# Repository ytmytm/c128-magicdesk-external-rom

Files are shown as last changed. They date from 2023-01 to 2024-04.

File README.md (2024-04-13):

# MagicDesk-like External ROM cartridge for C128

This is a clone of [Magic Desk 512k](https://github.com/msolajic/c64-magic-desk-512k) by Marko Šolajić
converted to KiCad 6 format and modified to work as an External ROM cartridge for C128 and map 32K of ROM at a time.

It is supported by [Magic cartridge generator](https://bitbucket.org/zzarko/magic-cartridge-generator/src/main/).

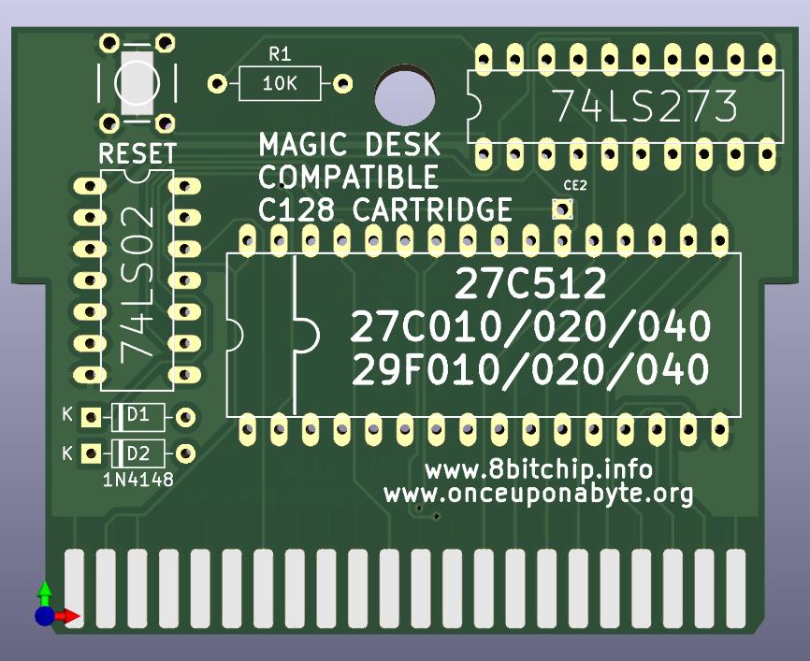
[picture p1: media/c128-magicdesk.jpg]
C128 External Function ROM cartridge


<a href="https://www.pcbway.com/project/shareproject/MagicDesk_like_External_ROM_cartridge_for_C128_43b0904b.html">PCB from PCBWay</a>

## Other options

There are two other projects [Magic Desk 128](https://github.com/RetroNynjah/Magic-Desk-128) and [Gmod2 (128)](https://www.freepascal.org/~daniel/gmod2/)
with a similar goal, but both map only 16K at a time. This makes it impossible e.g. to put The Servant on such cartridge.

## Why

It just seems much more useful in C128 mode to have whole 32K available - just like Internal Function ROM, but easily switched.
Since MMU can bank in/out both 16K halves ($8000-$BFFF) and ($C000-$FFFF) separately it seems that e.g. GEOS 128 could run directly from ROM bypassing any boot or loading parts.

## Hardware

The [schematic is here](kicad/plots/c128-magicdesk.pdf).

The main difference to C64 version is that this cartridge is meant for C128, so `/EXROM` signal is no longer connected to prevent from entering C64 mode automatically.

Two diodes and a pullup resistor perform AND function on `/ROML` and `/ROMH` to map 32K at a time ($8000-$FFFF).

Because the bank size is now 32K instead of 8K the lowest two bits of control register are not connected.

[kicad](kicad/) folder contains all the KiCad 6.0 project files and [kicad/plots](kicad/plots) all the Gerber files needed to produce PCB.

Please read the notes from the [original project](https://github.com/msolajic/c64-magic-desk-512k). The jumper configuration for various EPROMS/EEPROMS/FLASH chips is exactly the same, as well as possible expansion to 1MB.

## Programming

Data from ROM will appear as External Function ROM mapped in $8000-$FFFF area (32K).

ROM banks can be changed from BASIC.

```
BANK15:POKEDEC("DE00"),4*<rom bank>
```

There are 16 banks in a 512K EEPROM and 32 banks if you piggy-back two of them and connect `/CE2` signal as described for C64 Magic Desk 512K.

RESET will always enable bank 0.

It's easy to check the ROM data from C128 monitor, just use `8` as the bank number:

```
M 88000 880FF
```

Reading from $DE00 register will switch bank to a random value (what happened to be on the data bus), don't do that.

## Cartrige ROM generator

[Magic cartridge generator](https://bitbucket.org/zzarko/magic-cartridge-generator/src/main/) supports 32K banks, use `-832` option instead of `-8` when building ROM image.

A simple code snippet for a true C128 cartridge (internal/external function ROM) code to load and start BASIC program can be found on [World of Jani page](http://blog.worldofjani.com/?p=1600).

[Gmod2 Commodore 128 technical manual](https://www.freepascal.org/~daniel/gmod2/gmod2-c128.pdf) is also a useful resource.

You can also put The Servant on it. Preferably [the updated one that supports SD2IEC subdirectories and disk images](https://github.com/ytmytm/c128-theservant-sd2iec).

## Emulator Support

None yet :)

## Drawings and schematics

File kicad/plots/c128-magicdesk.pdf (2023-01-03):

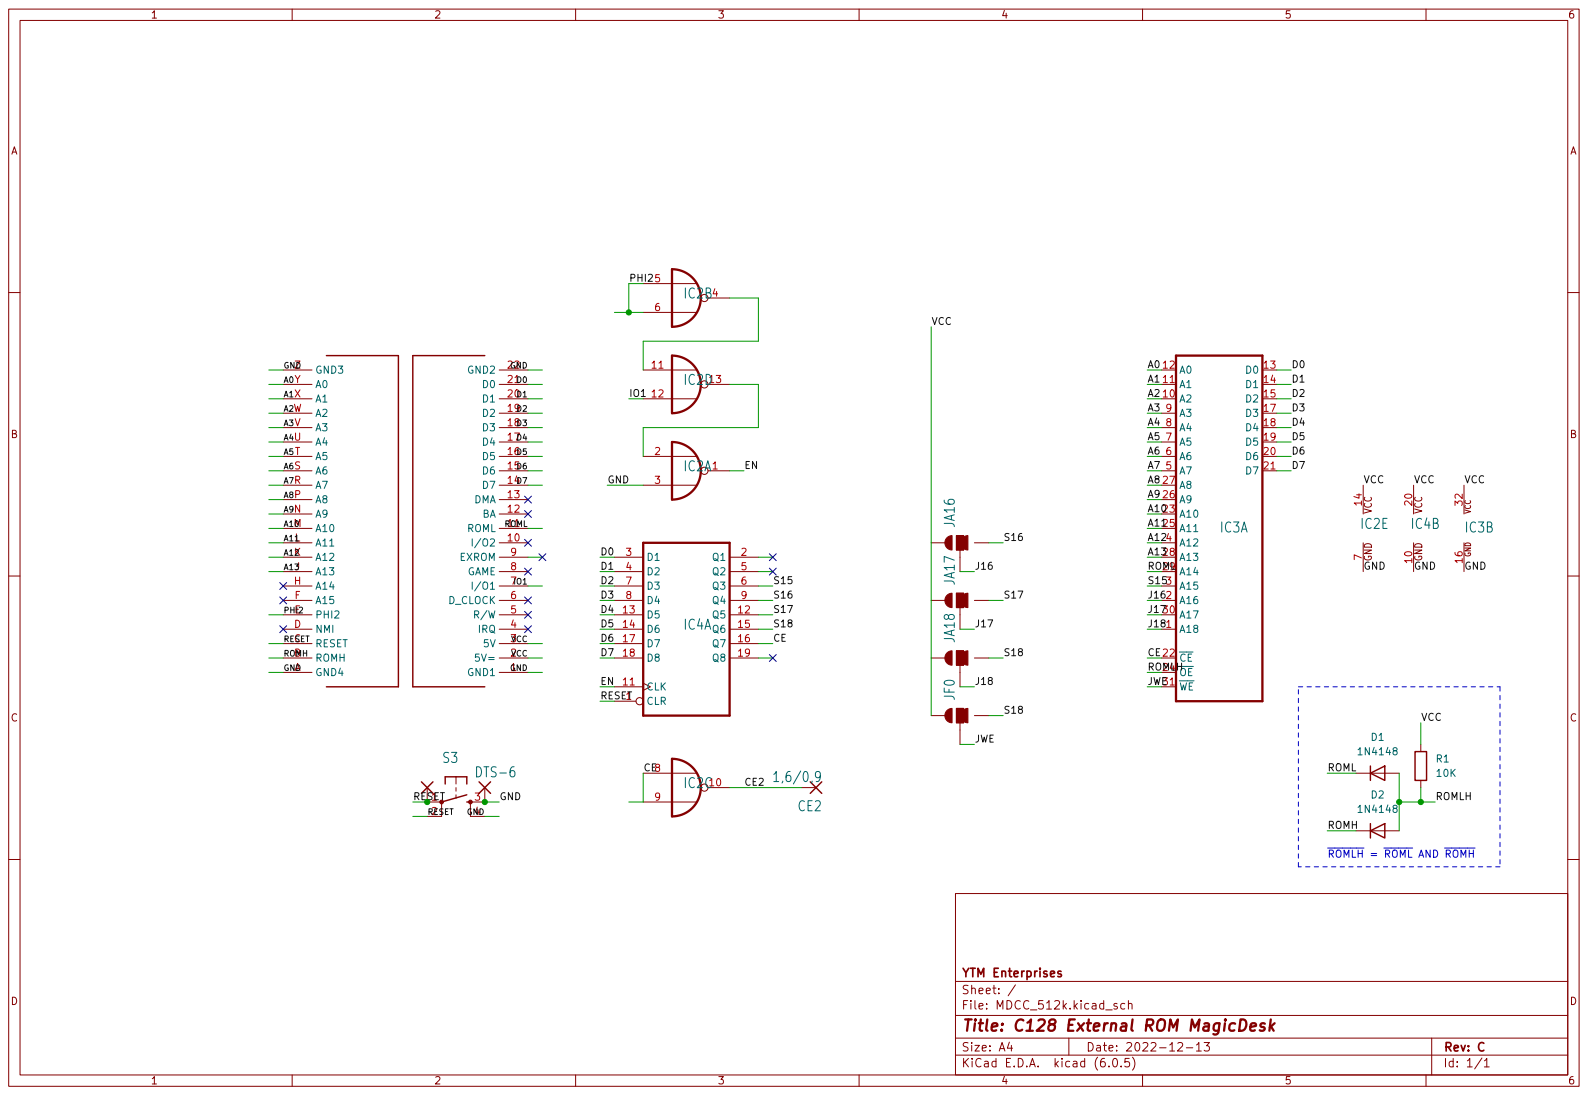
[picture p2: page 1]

~{ROMLH} = ~{ROML} AND ~{ROMH}

File: MDCC_512k.kicad_sch Sheet: / YTM Enterprises

Id: 1/1 Title: C128 External ROM MagicDesk

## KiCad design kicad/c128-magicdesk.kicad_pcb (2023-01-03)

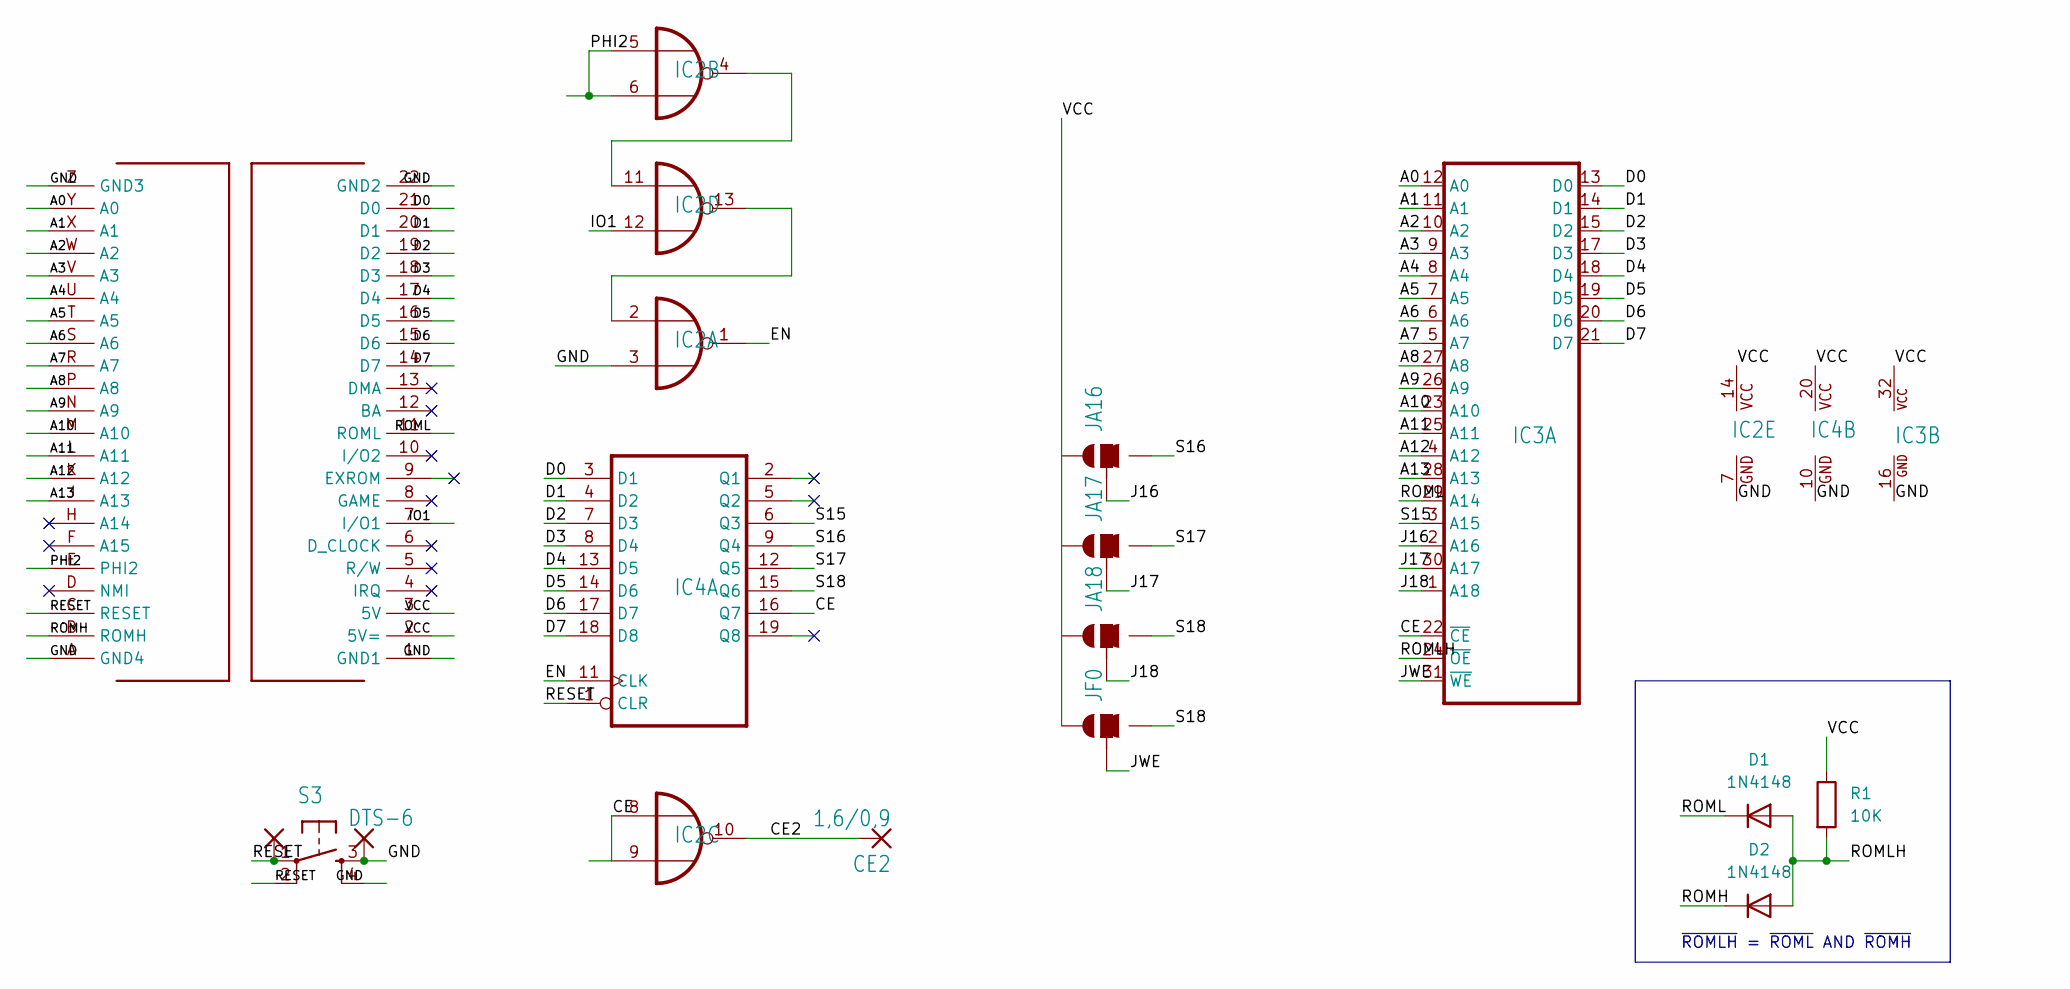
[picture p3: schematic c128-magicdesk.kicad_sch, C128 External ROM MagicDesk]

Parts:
CE2: 1,6/0,9; 1,6_0,9
D1, D2: 1N4148; D_DO-35_SOD27_P7.62mm_Horizontal
IC2: 74LS02; DIL14
IC3: 29F040; DIL32-6
IC4: 74LS273; DIL20
JA16, JA17, JA18: SOLDERJUMPER_2WAYS; SJ_3
JF0: SOLDERJUMPER_2WAYS; SJ_3
PAD1, PAD2: SMD5; SMD2,54-5,08
R1: 10K; R_Axial_DIN0207_L6.3mm_D2.5mm_P10.16mm_Horizontal
S3: DTS-6
U$1: C64_EXPANSION__CARTRIDGE

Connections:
/A0: IC3.12 (A0), U$1.Y (A0)
/A1: IC3.11 (A1), U$1.X (A1)
/A2: IC3.10 (A2), U$1.W (A2)
/A3: IC3.9 (A3), U$1.V (A3)
/A4: IC3.8 (A4), U$1.U (A4)
/A5: IC3.7 (A5), U$1.T (A5)
/A6: IC3.6 (A6), U$1.S (A6)
/A7: IC3.5 (A7), U$1.R (A7)
/A8: IC3.27 (A8), U$1.P (A8)
/A9: IC3.26 (A9), U$1.N (A9)
/A10: IC3.23 (A10), U$1.M (A10)
/A11: IC3.25 (A11), U$1.L (A11)
/A12: IC3.4 (A12), U$1.K (A12)
/A13: IC3.28 (A13), U$1.J (A13)
/CE: IC2.8 (I0), IC2.9 (I1), IC3.22 (~CE), IC4.16 (Q7)
/CE2: CE2.1, IC2.10 (O)
/D0: IC3.13 (D0), IC4.3 (D1), U$1.21 (D0)
/D1: IC3.14 (D1), IC4.4 (D2), U$1.20 (D1)
/D2: IC3.15 (D2), IC4.7 (D3), U$1.19 (D2)
/D3: IC3.17 (D3), IC4.8 (D4), U$1.18 (D3)
/D4: IC3.18 (D4), IC4.13 (D5), U$1.17 (D4)
/D5: IC3.19 (D5), IC4.14 (D6), U$1.16 (D5)
/D6: IC3.20 (D6), IC4.17 (D7), U$1.15 (D6)
/D7: IC3.21 (D7), IC4.18 (D8), U$1.14 (D7)
/EN: IC2.1 (O), IC4.11 (CLK)
/GND: IC2.3 (I1), IC2.7 (GND), IC3.16 (GND), IC4.10 (GND), PAD2.1, S3.3, S3.4, U$1.1 (GND1), U$1.22 (GND2), U$1.A (GND4), U$1.Z (GND3)
/IO1: IC2.12 (I1), U$1.7 (I/O1)
/J16: IC3.2 (A16), JA16.2
/J17: IC3.30 (A17), JA17.2
/J18: IC3.1 (A18), JA18.2
/JWE: IC3.31 (~WE), JF0.2
/PHI2: IC2.5 (I0), IC2.6 (I1), U$1.E (PHI2)
/RESET: IC4.1 (CLR), PAD1.1, S3.1, S3.2, U$1.C (RESET)
/ROMH: D2.1 (K), U$1.B (ROMH)
/ROML: D1.1 (K), IC3.29 (A14), U$1.11 (ROML)
/ROMLH: D1.2 (A), D2.2 (A), IC3.24 (~OE), R1.2
/S15: IC3.3 (A15), IC4.6 (Q3)
/S16: IC4.9 (Q4), JA16.3
/S17: IC4.12 (Q5), JA17.3
/S18: IC4.15 (Q6), JA18.3, JF0.3
/VCC: IC2.14 (VCC), IC3.32 (VCC), IC4.20 (VCC), JA16.1, JA17.1, JA18.1, JF0.1, R1.1, U$1.2 (5V=), U$1.3 (5V)
unnamed: IC2.4 (O), IC2.11 (I0)
unnamed: IC2.2 (I0), IC2.13 (O)

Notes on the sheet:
~{ROMLH} = ~{ROML} AND ~{ROMH}

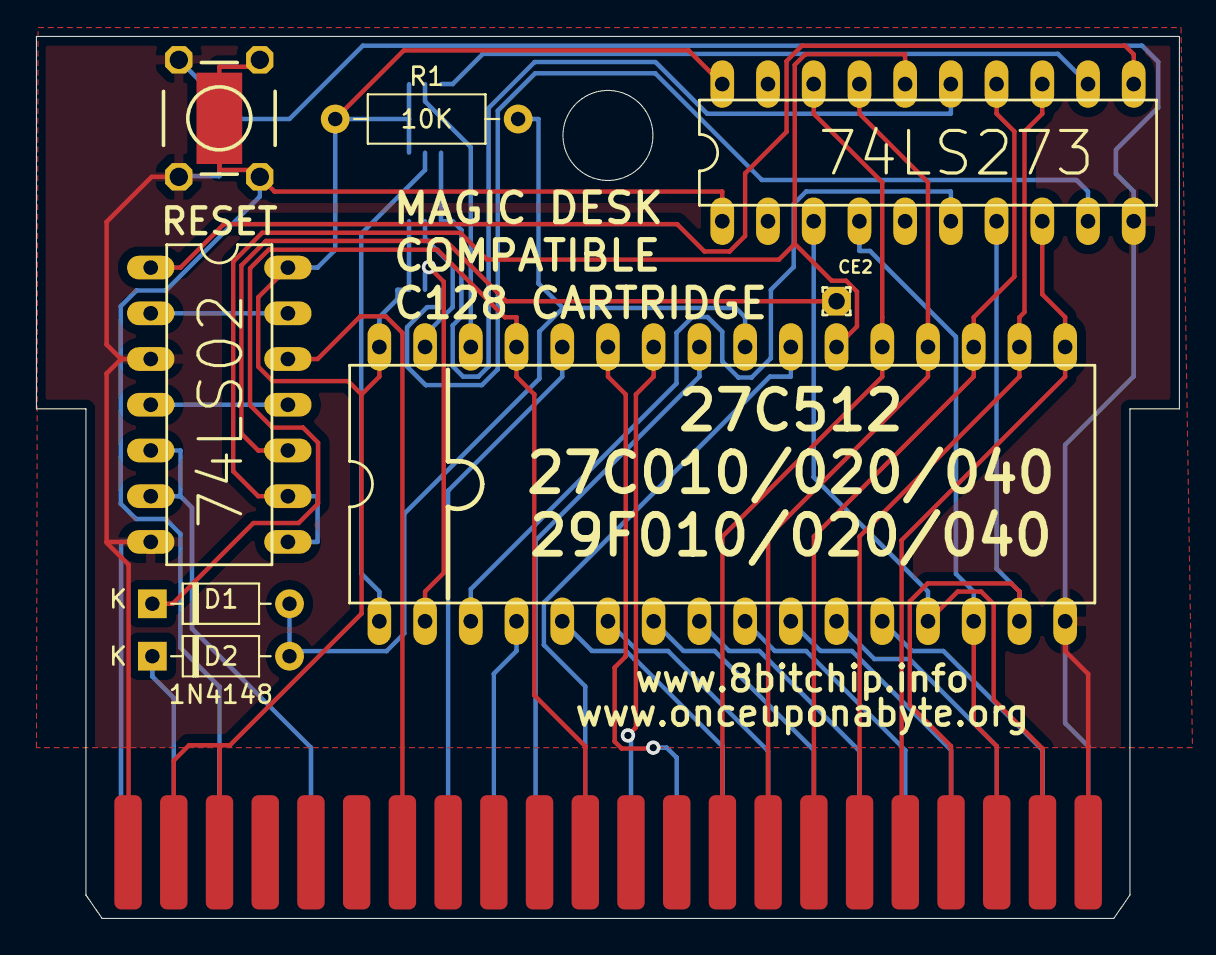
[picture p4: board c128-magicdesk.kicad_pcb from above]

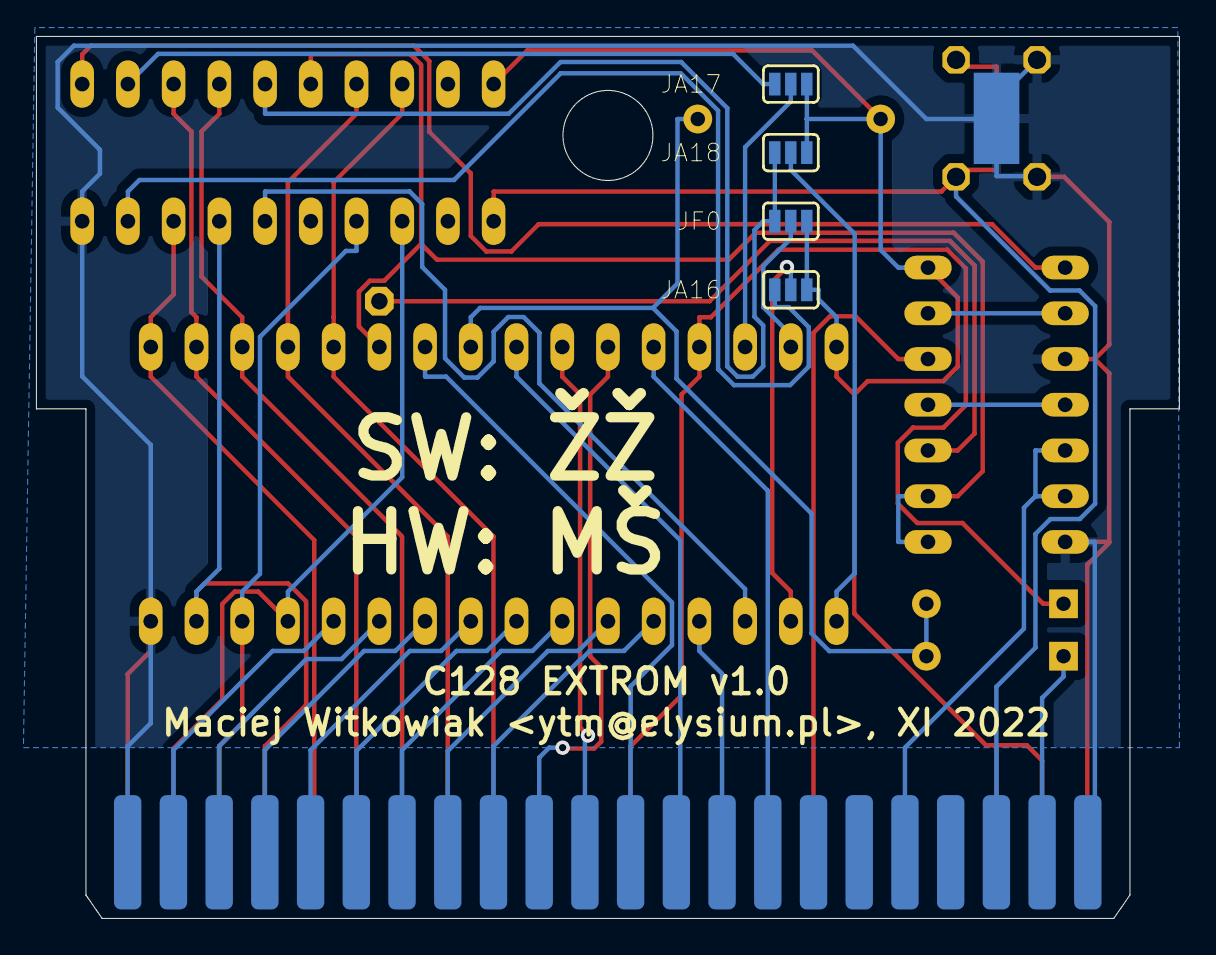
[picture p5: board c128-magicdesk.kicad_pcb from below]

Board: 2 copper layers, 63.5 x 49.0 mm, 15 parts (5 on the bottom side), 43 nets.
